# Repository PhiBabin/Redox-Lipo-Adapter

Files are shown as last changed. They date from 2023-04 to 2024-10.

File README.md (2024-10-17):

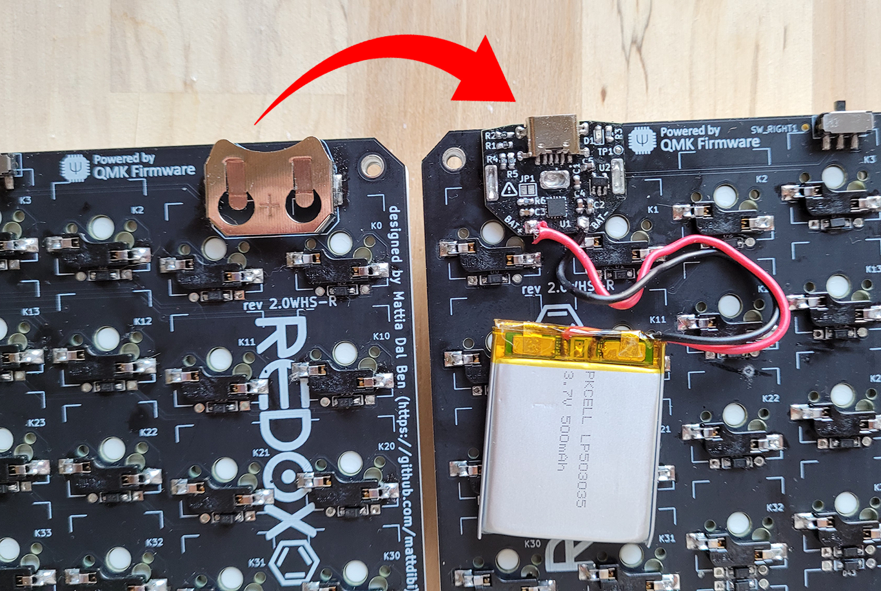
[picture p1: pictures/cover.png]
Original Redox next to the Redox with QUASO


# QUASO: A Rechargeable LiPo Adapter for Redox

Project **QUASO**: **Q**uick **U**sb **A**dapter for the wireles**S** red**O**x. This PCB replaces the coin cell battery of a [wireless Redox keyboard](https://github.com/mattdibi/redox-keyboard), it has a USB-C connector and circuitry to charge a LiPo battery. Gone are the days of buying disposable coin cell batteries for your wireless keyboard.

## Rationale

I really like my wireless Redox, however, I find that having to replace the coin cell battery is kind of annoying and wasteful. I could have just built a non-wireless Redox and changed the pro-micro to a Nice!Nano to get both wireless + rechargeable LiPo. But that would have been a waste, since it means building a brand new keyboard just to save on a few coin cells. Hence why I decided to design this mod.

## Build instructions

See [BUILD.md](BUILD.md) for the build and assembly instructions.

You can [find here](3d_printed_case/) a 3D printed case that accommodates a 503035 LiPo battery.

## Limitations

The USB-C connector is only used to charge the battery, it doesn't transmit data.

Because the PCB replaces the coin cell battery holder, the keyboard's on/off switch doesn't disconnect the LiPo battery from the battery management circuit. This means that when the switch is turned OFF, the battery will still consume a tiny bit of power, because it's powering the battery management chip and the voltage regulator. It also means that the battery can be recharged while the keyboard is turned off.

## Battery Life

For my redox, I choosed a [503035 500mAh battery](https://www.digikey.com/en/products/detail/adafruit-industries-llc/1578/5054539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). It took 6 months before I had to recharge the battery. Any 3.7V LiPo single cell battery should work with QUASO, but __IT MUST HAVE AN UNDERVOLTAGE PROTECTION__! Most small batteries have this kind of protection. Nano!Nice suggests using a 301230 battery (~100mAh) for a low power keyboard like the wireless Redox. For reference, a CR2032 coin battery as a capacity of around 225mAh.

## Pictures

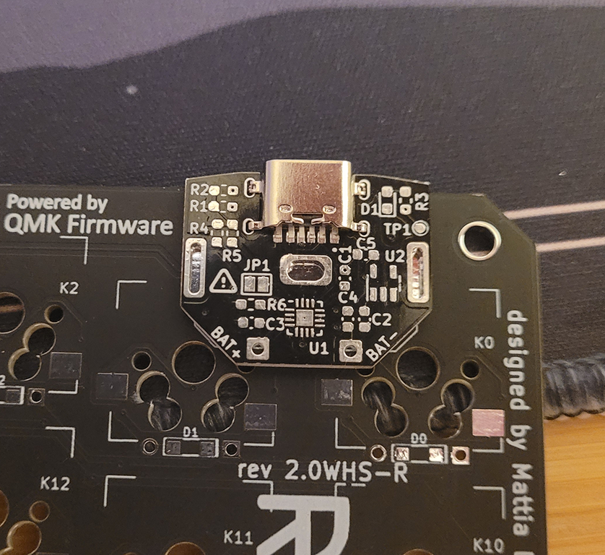
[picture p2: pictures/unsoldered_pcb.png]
Unsoldered QUASO PCB on top of a unsoldered redox PCB

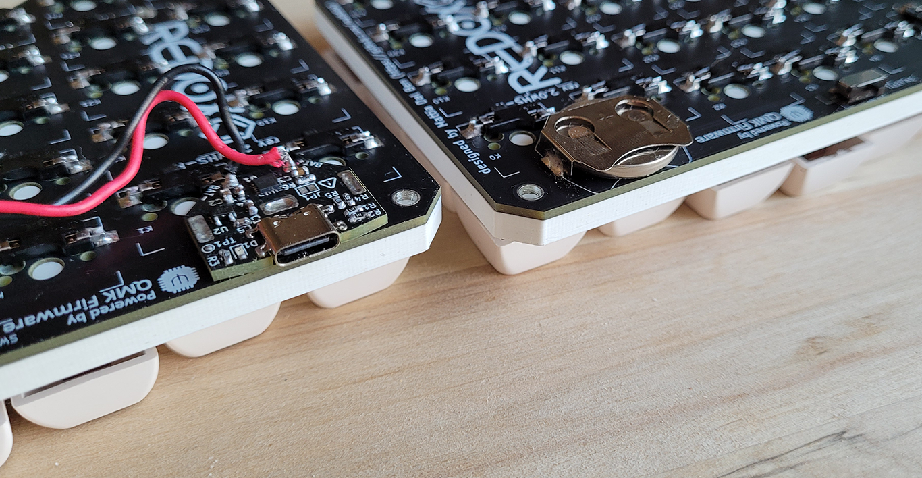
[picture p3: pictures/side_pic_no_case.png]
Side view of the QUASO next to the cell battery

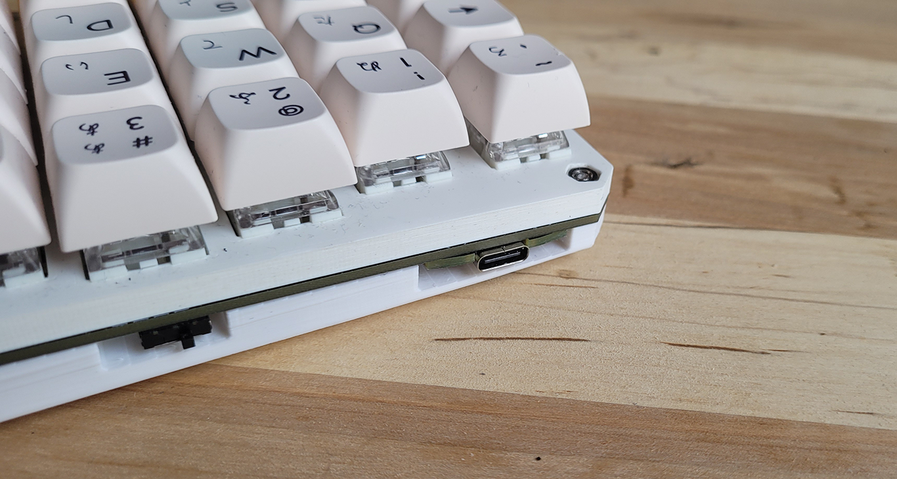
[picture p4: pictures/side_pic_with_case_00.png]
Side view of the QUASO with the case

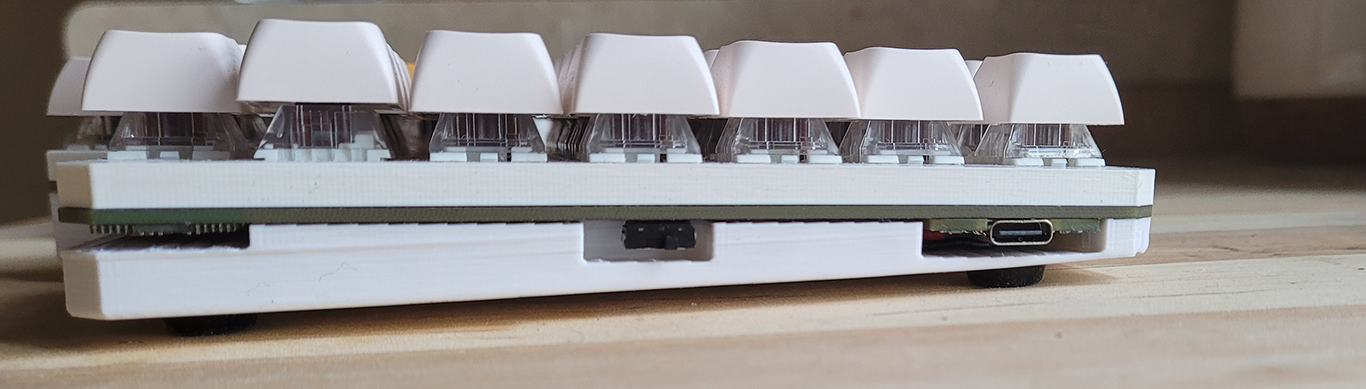
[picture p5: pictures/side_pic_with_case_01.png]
Side view of the QUASO with the case

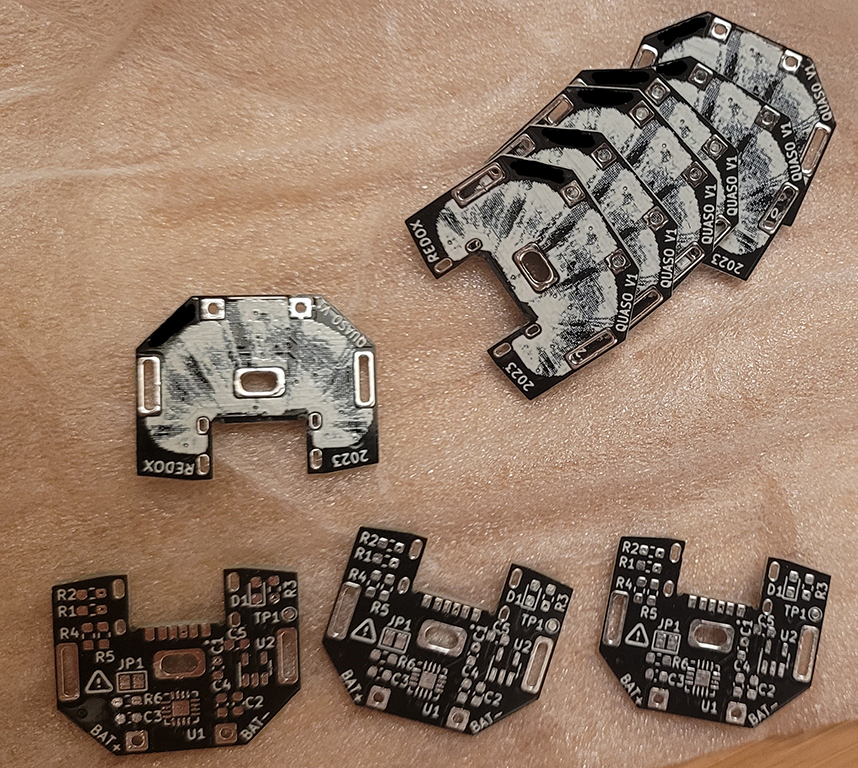
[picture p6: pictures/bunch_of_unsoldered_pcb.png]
Unsoldered QUASO PCB on top of a unsoldered redox PCB


## Change Log

- V1.0: Initial version [tested]
- V1.2: [tested by jadewolf05]
   - Change regulated voltage from 3.3V to 3V, the regulator will only cut off when the battery voltage reach 3.2V, instead of 3.5V.  
   - Change the USB connector for a part available on LCSL.
   - Swap of components to make JLCPCB assembly using  less extended components.
   - Make the top of the PCB flush with the keyboard's PCB.
- V1.3: [NOT TESTED]
  - Fix R1, R2, R4 and R5 not connected to GND.
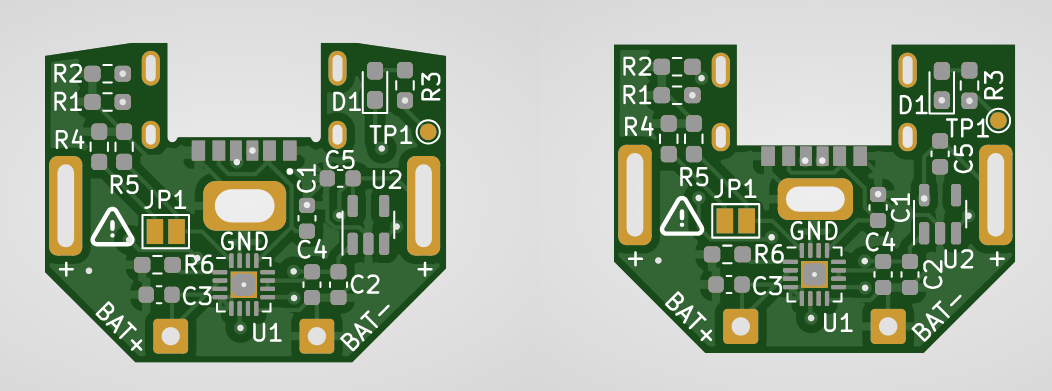
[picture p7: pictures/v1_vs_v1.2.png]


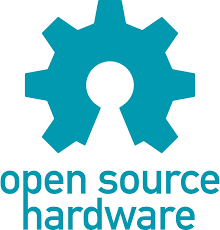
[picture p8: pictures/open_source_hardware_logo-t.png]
Open source hardware Logo


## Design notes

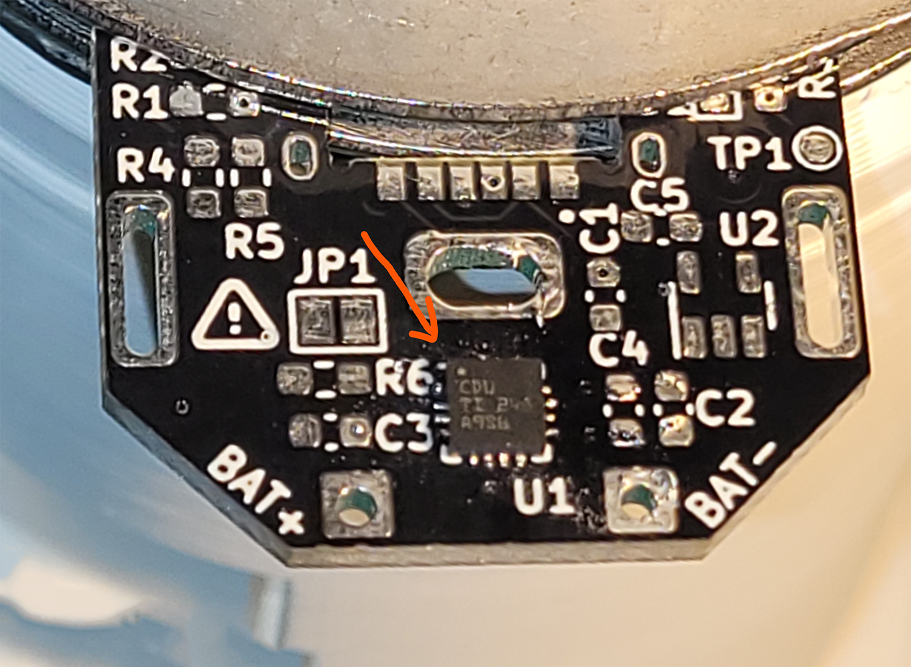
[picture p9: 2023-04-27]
pictures/alignment_u1.jpg.png

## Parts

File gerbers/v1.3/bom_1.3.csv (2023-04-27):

Designator | Footprint | Quantity | Value | LCSC Part #
C1, C4, C5 | 0603 | 3 | 1uF | C15849
C2, C3 | 0603 | 2 | 4.7uF | C19666
D1 | 0603 | 1 | LED | C72038
J2 | YTC-TC6-34_C2927284 | 1 | YTC-TC6-34 | C2927284
R1, R2 | 0603 | 2 | 5.1k | C23186
R3, R5, R6 | 0603 | 3 | 10k | C25804
R4 | 0603 | 1 | 2k | C22975
U1 | VQFN-16-1EP_3x3mm_P0.5mm_EP1.6x1.6mm_ThermalVias | 1 | BQ24075TRGTR | C544783
U2 | SOT-23-5 | 1 | TPS7A0330PDBVR | C3752328

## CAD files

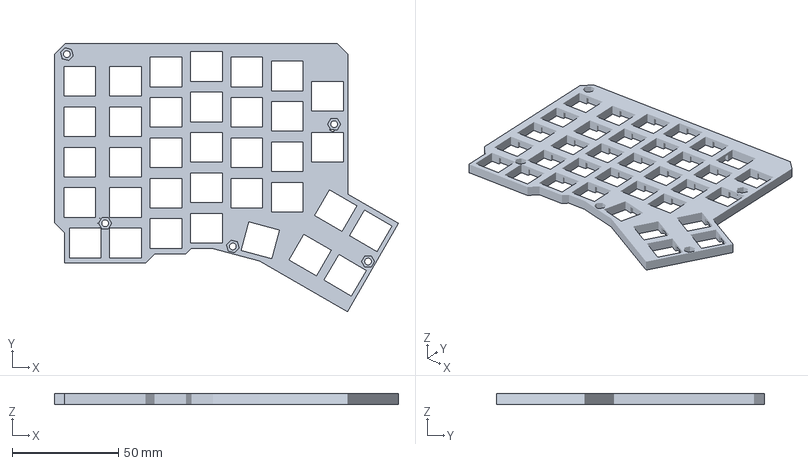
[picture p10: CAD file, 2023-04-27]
3d_printed_case/frontplate_left_hand.3mf
162.2 x 126.5 x 5.00 mm

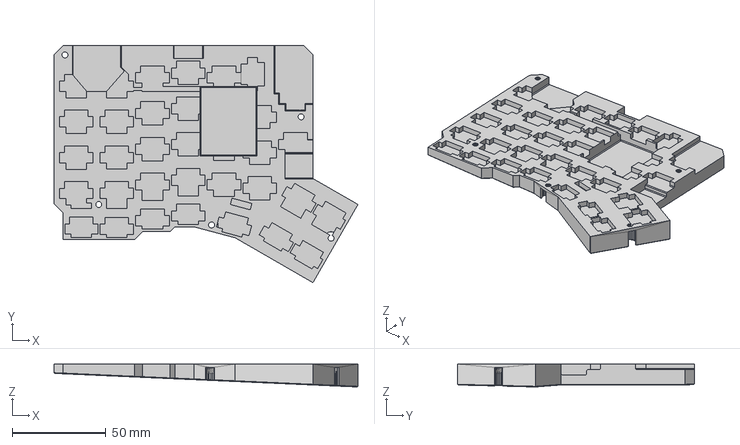
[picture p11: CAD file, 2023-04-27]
3d_printed_case/redox_case_with_battery.step
162.2 x 126.5 x 12.3 mm

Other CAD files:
3d_printed_case/backplate_left_hand_with_battery.3mf
3d_printed_case/redox_case_with_battery.f3d

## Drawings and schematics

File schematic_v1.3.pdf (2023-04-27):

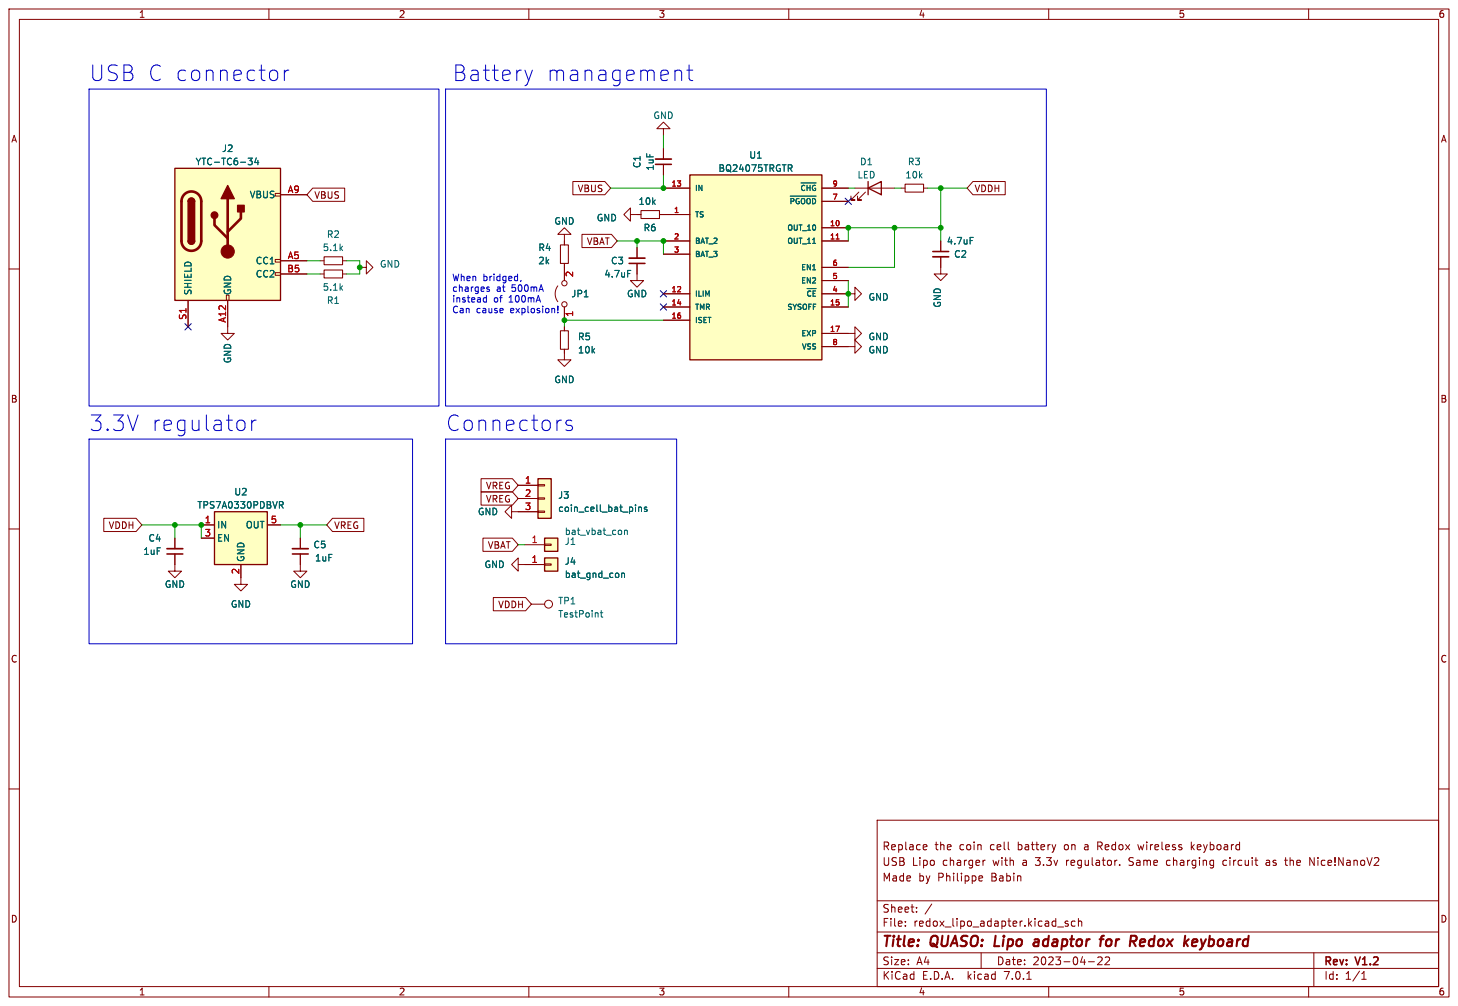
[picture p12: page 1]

Id: 1/1 Title: QUASO: Lipo adaptor for Redox keyboard

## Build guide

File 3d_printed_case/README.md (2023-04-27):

## 3D printed case

Side view of the QUASO with the case
Side view of the QUASO with the case
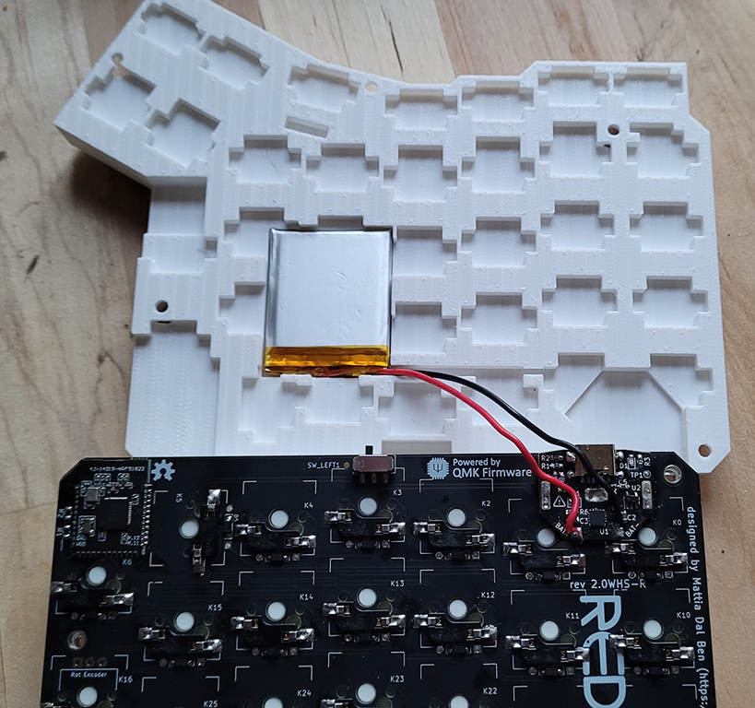
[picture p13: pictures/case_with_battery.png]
Open case with the battery


This is a modification of the [original Redox 3D printed case](https://github.com/mattdibi/redox-keyboard/tree/master/redox-w/rev2.0WHS/case) made by Mattia Dal Ben.

Changes:
 - Add cavity for a 503035 battery and to route its wire to the QUASO PCB
 - Add a ~3 degrees tilt to the case to keep the case mostly the same thickness  while having enough space for the battery
 - Hex insert for the nuts, making it much easier to assemble / disassemble

Printed in Hatchbox white PLA at 0.15 and 5% infill. I used supports for printing the screw holes on the backplate. In PrusaSlicer, I set the support style to "snug" to reduce the amount of support material on the exterior faces.

Hardware: 
 - 5x M3x8 screws
 - 5x M3 hex nuts
 - Double sided tape to hold the battery in place
 - (optional) [Rubber feet](https://www.amazon.com/dp/B06XCLYL53?psc=1&ref=ppx_yo2ov_dt_b_product_details)

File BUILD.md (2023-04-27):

# Build Guide

> **Warning**
> When jumper `JP1` is bridged, the battery will be charged at 500mA, instead of the default 100mA. Only bridge if your battery is above 500mAh and supports quick charge at 1C, **risk of explosion**!

## Bill of materials

| Qty | Ref ID | Item | Digikey | LCSC * |
|----:| :--: | ---| :---: | :---: |
| 2 |  | QUASO PCB |  | |
| 2 |  | 3.7V LiPo Battery |  | |
|  6 | C1, C4, C5 | 1u X5R 50V Capacitor | [Digikey](https://www.digikey.com/en/products/detail/tdk-corporation/c1608x5r1e105k080ac/2093414) | [LCSC](https://www.lcsc.com/product-detail/Multilayer-Ceramic-Capacitors-MLCC-SMD-SMT_Samsung-Electro-Mechanics-CL10A105KB8NNNC_C15849.html) | 
|  4 | C2, C3 | 4.7u X5R 25V Capacitor | [Digikey](https://www.digikey.com/en/products/detail/tdk-corporation/c1608x5r1e475k080ac/3648581) | [LCSC](https://www.lcsc.com/product-detail/Multilayer-Ceramic-Capacitors-MLCC-SMD-SMT_SAMSUNG_CL10A475KO8NNNC_4-7uF-475-10-16V_C19666.html) |
|  2 | D1 | Yellow LED 0603 | [Digikey](https://www.digikey.com/en/products/detail/liteon/LTST-C191KSKT/386839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) | [LCSC](https://www.lcsc.com/product-detail/Light-Emitting-Diodes-LED_Everlight-Elec-19-213-Y2C-CQ2R2L-3T-CY_C72038.html) |
|  2 | | USB-C power-only female connector | For V1.0: **  [Digikey](https://www.digikey.com/en/products/detail/gct/usb4515-gf-a/15635471) | For V1.2: [LCSC](https://www.lcsc.com/product-detail/USB-Connectors_YIYUAN-YTC-TC6-34_C2927284.html) |
|  4 | R1, R2 | 5.1k 5% 0603 Resistor | [Digikey](https://www.digikey.com/en/products/detail/stackpole-electronics-inc/RMCF0603JT5K10/1757959) | [LCSC](https://www.lcsc.com/product-detail/Chip-Resistor-Surface-Mount_UNI-ROYAL-Uniroyal-Elec-0603WAF5101T5E_C23186.html) | 
|  6 | R3, R5, R6 | 10k 5% 0603 Resistor | [Digikey](https://www.digikey.com/en/products/detail/walsin-technology-corporation/WR06X103-JTL/13239132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) | [LCSC](https://www.lcsc.com/product-detail/Chip-Resistor-Surface-Mount_UNI-ROYAL-Uniroyal-Elec-0603WAF1002T5E_C25804.html) | 
|  2 | R4 | 2k 5% 0603 Resistor | [Digikey](https://www.digikey.com/en/products/detail/yageo/9c04021a2001jlhf3/342353) | [LCSC](https://www.lcsc.com/product-detail/Chip-Resistor-Surface-Mount_UNI-ROYAL-Uniroyal-Elec-0603WAF2001T5E_C22975.html) |
|  2 | U1 | LiPo Battery Manager BQ24075RGTR | [Digikey](https://www.digikey.com/en/products/detail/texas-instruments/BQ24075RGTR/2047273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) | [LCSC](https://www.lcsc.com/product-detail/Battery-Management-ICs_Texas-Instruments-BQ24075TRGTR_C544783.html) |
|  2 | U2 | LDO 3V regulator TPS7A0330 | [Digikey](https://www.digikey.com/en/products/detail/texas-instruments/TPS7A0330PDBVR/12165132) | [LCSC](https://www.lcsc.com/product-detail/Linear-Voltage-Regulators-LDO_Texas-Instruments-TPS7A0330PDBVR_C3752328.html) |

*I haven't tried ordering the LCSC parts, they should work.

**Please note, that version 1.0 of the board uses [USB4515](https://www.digikey.com/en/products/detail/gct/usb4515-gf-a/15635471), while version 1.2 uses [YTC-TC6-34](https://www.lcsc.com/product-detail/USB-Connectors_YIYUAN-YTC-TC6-34_C2927284.html) as the USB-C connector. From checking the datasheet, it seems that USB4515 would fit on version 1.2 of the board, but I haven't tested it. 

### Battery Selection

Any 3.7V LiPo single cell battery should work with QUASO. Nano!Nice suggests using a 301230 battery (~100mAh) for a low power keyboard like the wireless Redox. For reference, a CR2032 coin battery as a capacity of around 225mAh. I used a [503035 500mAh battery](https://www.digikey.com/en/products/detail/adafruit-industries-llc/1578/5054539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) for my build. You can [find here](3d_printed_case/), a 3D printed case that fits the dimensions of the 503035. If you use a different battery, you'll need a different case.

## Instructions
The PCB is easy to solder by hand, except for the battery management chip (BQ24075). Because of the BQ24075, I **strongly recommend** you use a PCB assembly service to solder this PCB or use a stencil + solder paste. Beware that I have **NOT tested** the gerber files / BOM / CPT for assembly!

### Assembling by Hand the QUASO PCB
The first component to solder is BQ24075 (U1). I followed [this video](https://www.youtube.com/watch?v=X3Rc1s6EpSI) to solder the BQ24075 using a heat gun and a temperature probe:
1. Put flux and thin the pads. Put as little solder on the center pad as possible.
2. Clean up and reapply flux.
3. Place the BQ24075 on the PCB. Check that the dot on the chip is aligned like this:
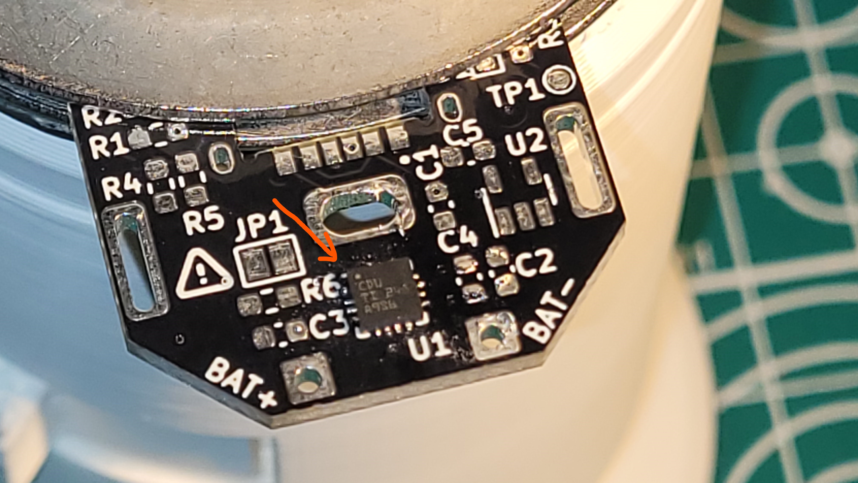
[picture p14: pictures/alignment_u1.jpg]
How to align U1

1. (Soak) Slowly heat the PCB using the heat gun over the course of 1-2min, until the PCB reaches a temperature of 150C.
2. (Reflow) Heat the PCB to 217C and hold it there for 30s. You should see the solder melting. The temperature and timing will depend on the type of solder you use.
3. (Cool) Slowly reduce the temperature back to 150C over the course of 1min by pulling back the heatgun. Then remove the heat gun and let it cool down.
4. Make sure that the chip is aligned with the pads. Check for shorts.

The other components are pretty straight forward to solder and can be done in any order. I soldered U2 first, then all the capacitors, the diode and resistors, and finally I soldered the USB connector.

Make sure that diode D1 is oriented correctly, by looking at the pad under the diode:
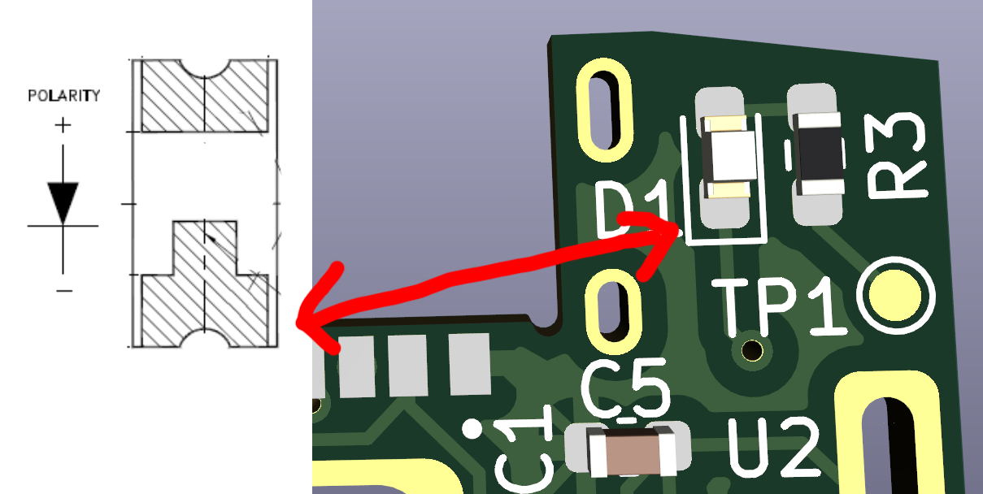
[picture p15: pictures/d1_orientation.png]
Orientation of D1


#### Testing
You can test that the USB port and 3V regulator is working correctly without the battery.
 - Plug the USB-C port and check the voltages you should see: 
   - 5V between test point TP1 and the ground
   - 3V between the holes on either side of the board and the ground. 

### Connecting the Battery
1. Cut the battery wires to length. If you're using a 503035 battery and my 3D printed case, leave at least 65mm of wire. 
2. Solder the battery's wires to BAT+ and BAT-. If you orient the wires towards the USB connector, it'll be slightly easier to close the case. 

If you're building the right hand Redox, make the battery wire go towards the right. If you're building the left hand Redox, do the opposite.

#### Testing
 - Check that when the USB is plugged in, the LED lights up.
 - Check that when the USB is not plugged in, the battery is providing power:
   - the voltage between BAT+ and ground should be the same as between test point TP1 and the ground;
   - And you should also see 3V between the holes on either side of the board and the ground;
 - Check that battery charging works: have the battery discharged to a voltage of less than 4.1V. Plug in the USB and check after half an hour if the voltage has increased.

### Soldering QUASO to Redox
1. Unsolder the coin cell holder from the Redox keyboard. Make sure to not use too much force when removing the holder.
2. Remove excess solder using a soldering wick.
3. Align the three holes on the QUASO to the pad on the Redox. Version 1.0 of the Quaso PCB doesn't sit flush with the border of the Redox PCB.
Unsoldered QUASO PCB on top of a unsoldered redox PCB

4. Once you're satisfied with the alignment, solder it to the PCB starting with the two 3V output holes. They don't have a ground plane, so they're much easier to solder first.
5. Solder the center ground hole.

#### Testing
 - Test that you're getting 3V on the pin of the power switch.
 - Test that when the switch is ON, you still get 3V

#### Finished assembly
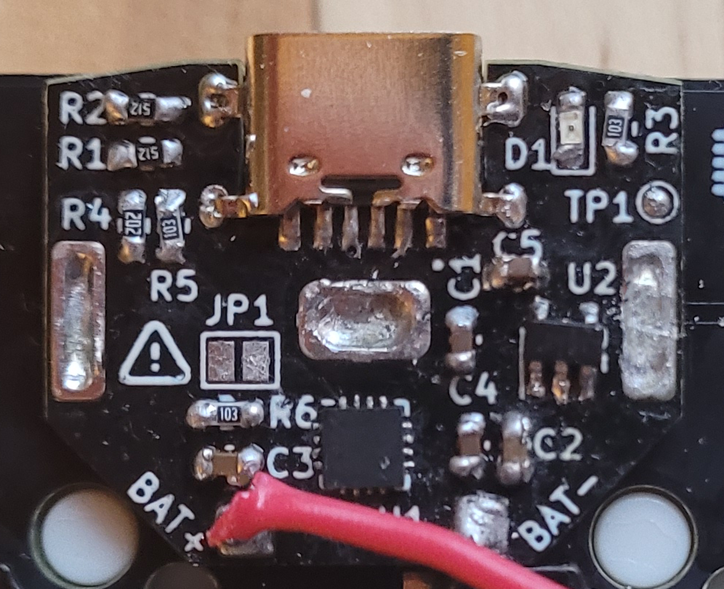
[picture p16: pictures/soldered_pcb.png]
QUASO soldered

Hopefully you did a better soldering job than me...

### Fitting in the Case
This assumes you're using the 3D printed case:
1. Put double sided tape on the battery.
2. Insert the battery in its receptacle in the bottom case.
Open case with the battery

3. Pass the battery's wires in their trench.
4. Close the bottom case while making sure that the wires are not pinched by the case.
5. Screw the bottom case.

## Troubleshooting
##### USB works, but when powered by only the battery, no power is output by BQ24075
I had this issue on both of my PCB. Some of the pins on the BQ24075 were not properly connected. I solved it by using a soldering iron to solder the four sides of the BQ24075. In my case, the main culprit  was pin 15 (this pin disables/enables the battery output), since it's directly connected to ground, it takes more heat to properly solder it.

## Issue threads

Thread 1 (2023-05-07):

QUASO to integrate.

azhizhinov, 2023-05-07:
Hello.
I've remade the Redox keyboard with modern footprints.
We can add the QUASO at this PCB, as I can see, so I can share my KiCAD project files with you, if you interested in that.
And may I ask you about possibility to replace of BQ24075TRGTR with something more comfortable to solder with iron.
Thanks for your time.
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

PhiBabin, 2023-05-15:
Yeah, the BQ24075TRGTR is kind of a pain to solder... Since your board seems to support the Pro-micro layout, probably the best way to get both wireless and LiPo battery is to use a Nice!Nano.

This wiki page is really good overview of all the battery charger chips, most of the chips in there are easier to soldier:
https://github.com/joric/nrfmicro/wiki/Batteries

azhizhinov, 2023-05-15:
Ok, thanks.

Closed 2023-05-15.

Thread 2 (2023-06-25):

Battery not charging

jadewolf05, 2023-06-25:
I made 2 of these(v1.2) and both have the same issue with the battery not charging.

When plugged in:
both have the charge led on.
5.1v between tp1 and gnd
battery voltage is present between gnd and both outside positive terminals that go to the redox when usb is unplugged.
battery voltage is present between gnd and tp1 when unplugged.
Battery voltage never increases(3.890 on one and 3.896 on the other)
USB ammeter also shows no current draw when plugged in.

Please let me know if anyone else is seeing this issue with V1.2 or if any other data is needed to determine why it isn't charging.

so far I have not installed them into my redox since they will not charge.

jadewolf05, 2023-06-25:
I've also noticed that no gnd is present on the gnd side of R2,R1,R4, and R5.  I also don't see a connection in the gerber files.  I have tried grounding the gnd side of those resistors, but no change in behavior.

jadewolf05, 2023-06-25:
missing gnd on R1,R2,R4, and R5 didn't sit right with me so I pulled up the datasheet for the BQ24075 and found that ISET(pin 16) is connected to R5 and per the datasheet, if ISET is disconnected charging is disabled.
I tried grounding those resistors before, but after it was already connected.
I ran a jumper wire this morning to give those resistors ground on startup and BAM... now its charging.

Hope this helps someone else running into this issue with V1.2.

jadewolf05, 2023-06-25:
For anyone reading this with the same issue.
TLDR:
V1.2 doesn't have a GND connection on R1,R2,R4, and R5.
Run a jumper wire to give it ground or it will not charge.

PhiBabin, 2023-08-16:
Sorry for late reply.
I'm really sorry for that stupid mistake. Should have triple checked v1.2 before uploading it. I pushed v1.3 which is the same as v1.2, but with the missing via.
Sorry again for the troubles.

Closed 2023-06-25.

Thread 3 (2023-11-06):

Regulated voltage level?

neopostmodern, 2023-11-06:
I come here from [this issue](https://github.com/mattdibi/redox-keyboard/issues/156#issuecomment-1783868794) and am interested in integrating this into my Redox. While looking through the repo I got confused about the regulated voltage of the most recent design.
At the bottom of the README it says "Change regulated voltage from 3.3V to 3V", but [the schematic](https://github.com/PhiBabin/Redox-Lipo-Adapter/blob/main/schematic_v1.3.pdf) mentions a "3.3V regulator" with no further specification of `VREG`. So – which is it?

I'm asking because my current hypothesis to mitigate connectivity issues I'm facing is running the Redox at a [slightly elevated voltage](https://github.com/mattdibi/redox-keyboard/issues/55).

PhiBabin, 2023-11-13:
V1.0 has a 3.3V regulator. V1.2 and V1.3 used a 3V regulator. In theory, you get better battery life with a 3V regulator, since you can use the 4.2V to 3.0V range of the battery. I don't know if it actually makes a significant difference in practice, since the Li-po's voltage is not linear with the state of charge. So if you're worry about low voltage, using the 3.3V should be fine. The microcontroler (nRF51822) used by the Redox support an input voltage between 1.8V and 3.6V.

Closed 2023-12-07.

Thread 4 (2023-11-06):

Battery life per charge?

neopostmodern, 2023-11-06:
Are there any experiences yet how far one gets on a single battery charge (assuming the mentioned 500mAh)? Would it make sense to bother with a larger battery?

PhiBabin, 2023-11-13:
I charged my keyboard at the end of April and I have not charged since then. Last time I checked 2 weeks ago, it had 3.465V.

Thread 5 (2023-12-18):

Discrepency with BOM link / description

o-klp, 2023-12-18:
Thanks for putting this repo up and keeping split keyboards accessible

I noticed the [Bill of Materials](https://github.com/PhiBabin/Redox-Lipo-Adapter/blob/main/BUILD.md#bill-of-materials) lists C1, C4 and C5 as 50v-rated capacitors. But the included Digitkey link points to 25v-rated ones.

Is it safe to use the 25v ones for those connections? I assume the voltage is low enough here given the components, but don't know what USB C can top out at

PhiBabin, 2023-12-22:
I don't think the voltage rating matter for this application. The USB charging only got up to 5V.

Closed 2023-12-22.

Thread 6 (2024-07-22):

Yellow light issue

OrvilleQ, 2024-07-22:
The yellow LED only lights up once when the USB is connected, instead of staying consistently lit when the USB is plugged in. This happens whether the battery is soldered on or not.

Is this the normal behavior of this board?

PhiBabin, 2024-07-27:
On both of my board it stay light up when the USB is connected (they have a battery connected, but the batteries are not fully charged). [Page 20 and 26 of the bq24075 datasheet](https://github.com/PhiBabin/Redox-Lipo-Adapter/blob/main/datasheets/bq24075.pdf) shows a diagram of state machine that control the CHG pin of the yellow light. Maybe your battery is just already charged?

PhiBabin, 2024-07-28:
I tried disconnecting the battery from the board and connecting the USB, and the yellow light only lights up once and then it shutdown.

OrvilleQ, 2024-07-29:
After re-soldering the BQ24075RGTR, the yellow light is always on when the USB is plugged in with the battery already connected. So this may be a different manifestation of the same problem as the battery not working, because you also reproduced that when there is no battery connected, the yellow light only comes on once, which seems to be normal behavior.

OrvilleQ, 2024-09-20:
Hi, I have another question.

After charging the battery for about 6 hours using the computer's USB port, the yellow light is still on, which makes me wonder if there is a way to identify if the battery is fully charged?

OrvilleQ, 2024-09-23:
Also the battery connected to the board can only been charged to 3.9V, 4.0V is the best. Is that by design? Sorry for this kind of basic questions, I only have limit knowledge about electricity, and it's my first time soldering a board myself. I tried to read the battery IC's document but cannot understand a bit of it :( .

Thanks for your help.

PhiBabin, 2024-09-28:
Interesting, BQ24075 should be charging to 4.2V. I don't know what could be causing this, like the [ battery IC's datasheet charge state flow diagram(p.26)](https://github.com/PhiBabin/Redox-Lipo-Adapter/blob/main/datasheets/bq24075.pdf) it seems like it'll keep charging until the charging current goes down to `I_term` (`I_term = 0.1 * I_chr = 10mA` ). I don't really understand how LiPo battery actually get charged, but maybe the charger just send current to the battery until either 4-6h (T_MAXCHG) has elapsed or if the current going in the battery as lower below `I_term`. If this is true, that would mean that the LiPo battery is not taking in any current once it reaches 4V or that it takes too much time to charge. I think it would be best if you just use your keyboard regularly and once it reach 3.3V or something, see if you can recharge it back to 4V.

I can try charging my keyboard for a few day and seeing the voltage I get. I vaguely remember getting 4.1V when I first build that keyboard, but that was a while back.

OrvilleQ, 2024-10-01:
Thank you for your reply. After communicating with the seller of the battery and observing and measuring the voltage of a keyboard that has been in normal use for a while, I currently suspect that the issue with charging the battery to 4.2V is related to the settings of the built-in protection board. I happen to be on vacation right now, and I will find time to disassemble the keyboard and test the charging current.

However, a new problem has arisen: besides my own keyboard, I also made one for a friend. His keyboard is unable to charge. After measuring, I found that the voltage of the two lithium batteries in his keyboard is 2.5V, indicating significant over-discharge. When I sent him the keyboard, I did not charge his batteries, so the only possibility I can think of is that the lithium battery module, due to being unable to enter sleep mode, continuously drew power from the nearly empty lithium batteries, ultimately leading to over-discharge. Is this possible? When the battery voltage is low, does this lithium battery module have a mechanism to protect the battery from over-discharge, and does it provide some visual indication (like a yellow light)?

Current issues:

1. The battery cannot be charged to 4.2V (I will test the charging current in the next few days).
2. Is there a visual indication for low battery and fully charged battery?
3. Is there a protection mechanism for low battery voltage?

I will provide further testing information as soon as possible. Please let me know if there are any tests you need me to conduct. Thank you.

PhiBabin, 2024-10-07:
The circuit has no under voltage protection, so it'll drain the battery if the keyboard is left on. This is a mistake on my part, I misunderstood the LDO worked and assumed that at <3V it would shutdown. I based the circuit on the Nice!Nano! v2 and [looking online](https://www.reddit.com/r/olkb/comments/1ajjl9m/can_i_use_these_batteries_with_my_nicenano_clones/kp3ab2f/) it seems that the circuit was designed with the expectation that the battery has its own undervoltage protection. I'm really sorry about that.

I'll look into and see if I can find an easy fix, but it seems that I'll probably have to redesign the board with a different Battery Manager chip (one with undervoltage protection) or with an additional under voltage protection circuitry.

OrvilleQ, 2024-10-08:
@PhiBabin Thank you for your response. I don't believe using batteries with protection circuits constitutes a design flaw on your part, because most of the soft-pack lithium batteries available today, at least from my perspective, come with protection circuits. In fact, the two batteries that were over-discharged also had protection circuits, and their cutoff voltage for discharge should have been 2.75V. I don't see this as a design defect that requires fixing—perhaps just adding a note in the documentation would suffice.

As for my progress, the new lithium batteries I ordered from another vendor have finally arrived. Upon receiving the batteries, I measured the voltage, which was 3.982V.

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

I connected the lithium battery and multimeter in series with the circuit on the lithium battery board and measured the idle current consumption of the battery board to be 20uA， and when a button is pressed, the current consumption is approximately 10mA.

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

Finally, I plugged the charging port into the circuit board. When the yellow light turned on, indicating the start of charging, the circuit board was still consuming around 17uA of current. It seems that the current is not being delivered to the battery at all.

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

Since the battery I purchased supports 1C charging, I also tried shorting JP1 for the experiment, but the situation remained basically the same as when it was not shorted.

OrvilleQ, 2024-10-09:
The board pass most of the test you mentioned in BUILD.md, including:

- Plug the USB-C port and check the voltages you should see:
  - 5V between test point TP1 and the ground
  - 3V between the holes on either side of the board and the ground.

- Check that when the USB is plugged in, the LED lights up.
  - Check that when the USB is not plugged in, the battery is providing power:
  - the voltage between BAT+ and ground should be the same as between test point TP1 and the ground;
  - And you should also see 3V between the holes on either side of the board and the ground;

The only test I didn’t follow strictly was the charging test. The steps I followed at the time were:

1. After soldering the battery, I turned on the keyboard switch but found the keyboard wasn't working.
2. I plugged in the USB-C port and observed the yellow light turning on. After a while, I unplugged it and found the keyboard was working fine.
3. I felt everything was okay and assumed the charging was successful, though I didn't measure the voltage during the process.

Just bought a tool for discharging the battery. I plan to discharge the battery to around 3V and then recharge it to see if it can charge properly.

PhiBabin, 2024-10-17:
> Thank you for your response. I don't believe using batteries with protection circuits constitutes a design flaw on your part, because most of the soft-pack lithium batteries available today, at least from my perspective, come with protection circuits. In fact, the two batteries that were over-discharged also had protection circuits, and their cutoff voltage for discharge should have been 2.75V. I don't see this as a design defect that requires fixing—perhaps just adding a note in the documentation would suffice.

I'll update the README.

I let my keyboard charge for a week and it got charged to 4.1V,  which match the voltage I was getting when I first build the board.

> 1. After soldering the battery, I turned on the keyboard switch but found the keyboard wasn't working.
> 2. I plugged in the USB-C port and observed the yellow light turning on. After a while, I unplugged it and found the keyboard was working fine. (the charge could be less than 20 seconds on some board)
> 3. I felt everything was okay and assumed the charging was successful, though I didn't measure the voltage during the process.

Thanks for taking the time to test your battery! So you're getting only 20 seconds of charge on a ~3.9V battery? It sounds like there is something not properly soldered, for instance, if the ISET pin is not properly soldered, charging is disabled.
Just to confirm, you're on board v1.3? Because V1.2 has an issue where this pin was not routed properly (R1, R2, R4 and R5 weren't connected to GND). FYI, I'm on board V1.0, so it's totally possible that I made another mistake on v1.3.

Looking at the gerber file for V1.3, I noticed that the via for R2 might be too far away from the pad. Could you check the continuity between the  CC1 pin of the USB and R2? In the following screenshot I have put an arrow on the via that might be too far from the pad:
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

Note: CC1 is only relevant for USB-C to USB-C, for USB-A to USB-C, it should have no impact.

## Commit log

2023-04-27 Init commit with all information for v1 and v1.2
    [backplate_left_hand_with_battery.3mf, bom_1.2.csv, bom_v1.csv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]
2023-08-16 v1.3: Fix R1, R2, R4 and R5 not connected to GND
    [bom_1.2.csv, bom_1.3.csv, positions_1.2.csv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]
